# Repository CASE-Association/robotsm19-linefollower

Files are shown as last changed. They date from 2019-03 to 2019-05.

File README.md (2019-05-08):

# CASE line follower robot 2019
Project repository for CASE hardware and software developement for attending the Swedish Robotic Championship 2019.
The robot got 2nd place in the Swedish Robotic Championship 2019.
Diploma

### Contributors
    -   Oskar Johansson
    -   Isak Åslund 
    -   Stefan Larsson

### Structure
    -   Software - All code for running the robot, implemented on Arduino   
    -   Hardware - PCB and hardware design
        -   Schematics for Arduino & STM32F103C8

### Pictures
[Picture album](https://imgur.com/a/kjrejrC)

**V0.1**
Initial Concept

**V0.2**
Working prototype

**V1.0**
Competition design

**PCB**
Two PCBs was designed, one for arduino and one for STM32.
Due to battery being applied to the VB pin on the STM32 it burned up. 
This caused us to use an arduino nano with breadboard instead. 
Since then a updated PCB has been made.
CASE STm32 PCB

### Pinout Help
https://components101.com/microcontrollers/arduino-nano

### Info for development
IDE - Visual Studio Code + PlattformIO
If you want to simplify development change the formatter for cpp to the following:
"{ BasedOnStyle: Google, IndentWidth: 4, ColumnLimit: 0}", more info [here](https://stackoverflow.com/questions/46111834/format-curly-braces-on-same-line-in-c-vscode)

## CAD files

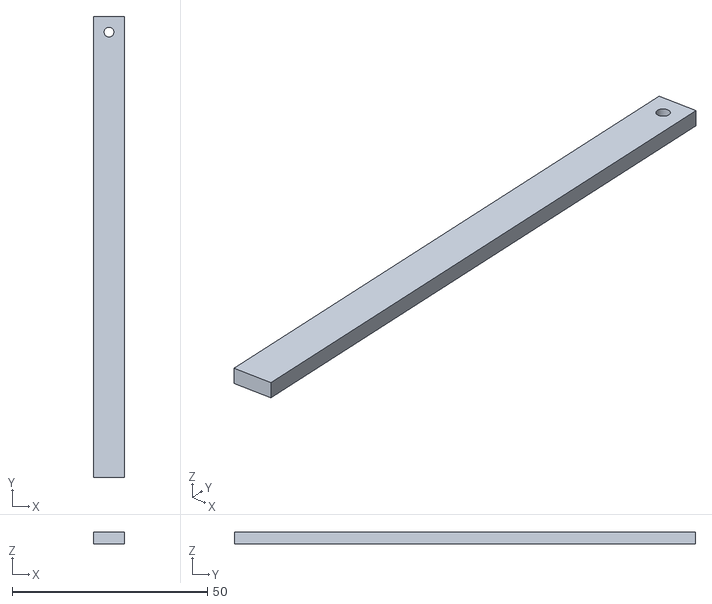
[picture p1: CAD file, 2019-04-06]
hardware/sensorExtender.stl
8.00 x 118.0 x 3.00

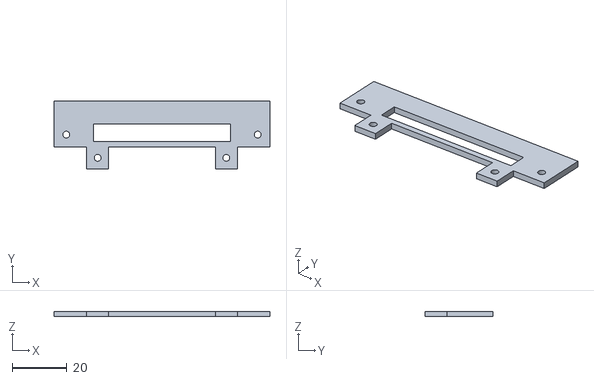
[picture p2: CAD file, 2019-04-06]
hardware/sensormount.stl
78.9 x 24.7 x 2.00

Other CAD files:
hardware/cad/Body.ipt

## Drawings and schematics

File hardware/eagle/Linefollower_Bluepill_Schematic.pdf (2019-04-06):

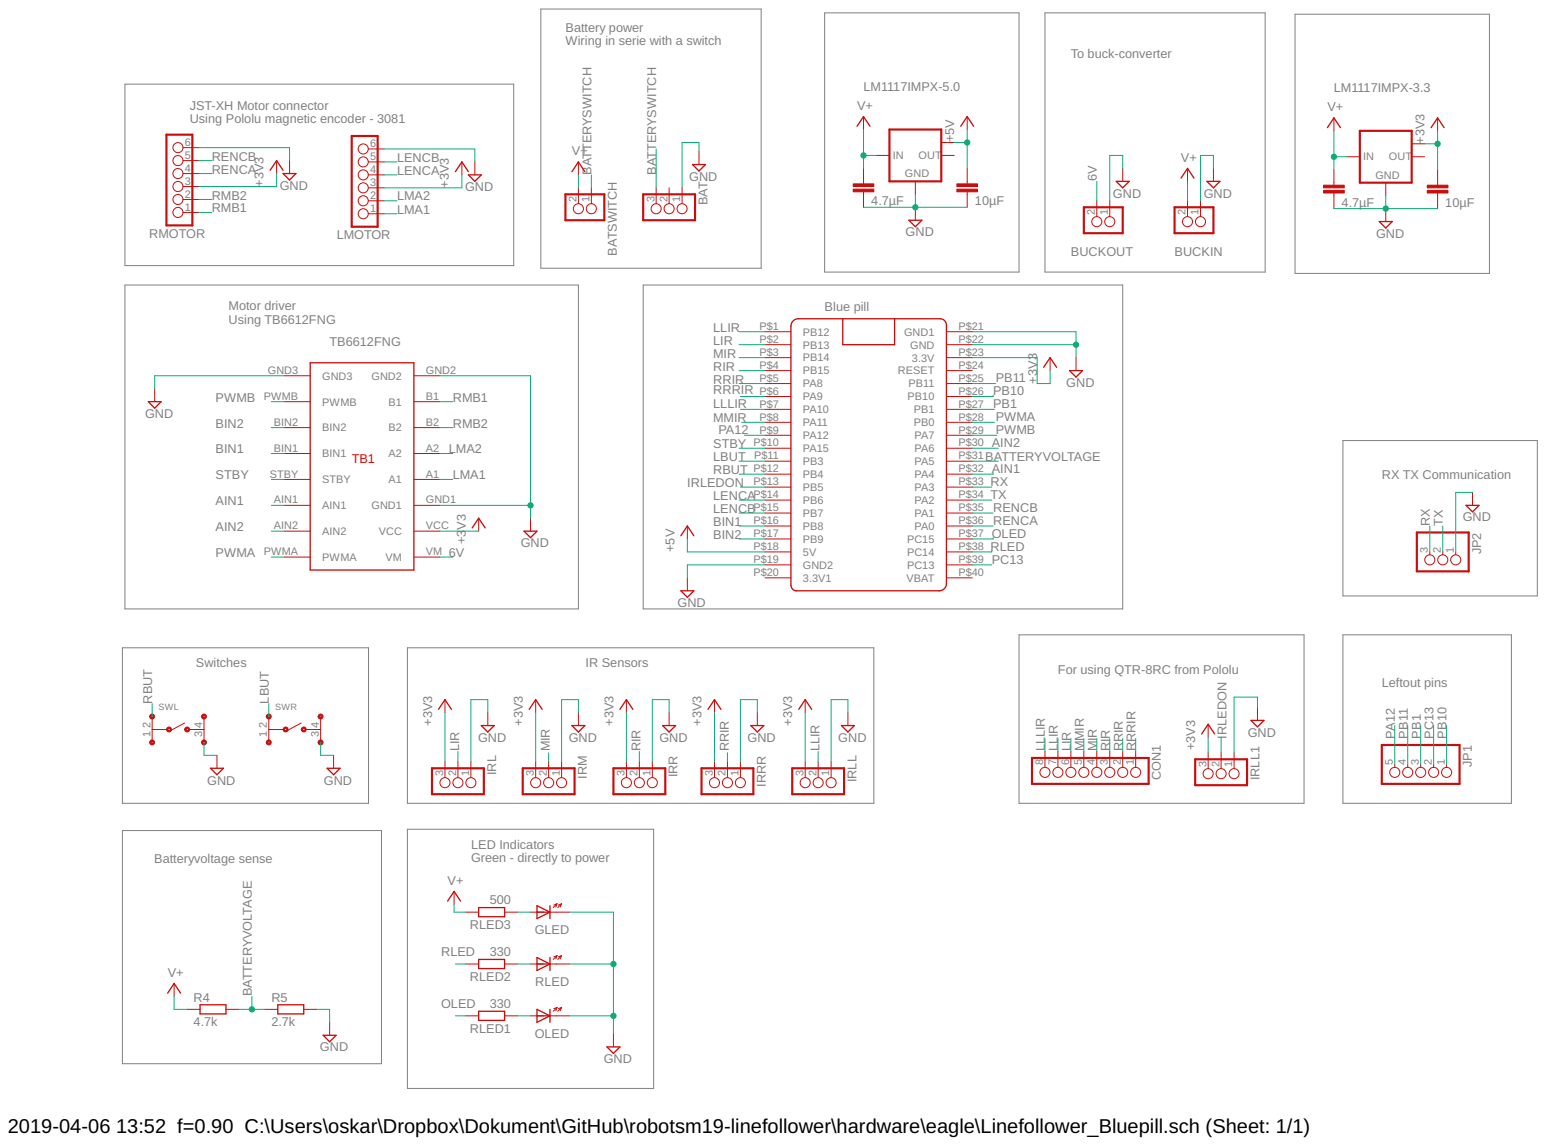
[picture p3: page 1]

Battery power Wiring in serie with a switch

JST-XH Motor connector Using Pololu magnetic encoder - 3081

For using QTR-8RC from Pololu

LED Indicators Green - directly to power

2019-04-06 13:52 f=0.90 C:\Users\oskar\Dropbox\Dokument\GitHub\robotsm19-linefollower\hardware\eagle\Linefollower_Bluepill.sch (Sheet: 1/1)

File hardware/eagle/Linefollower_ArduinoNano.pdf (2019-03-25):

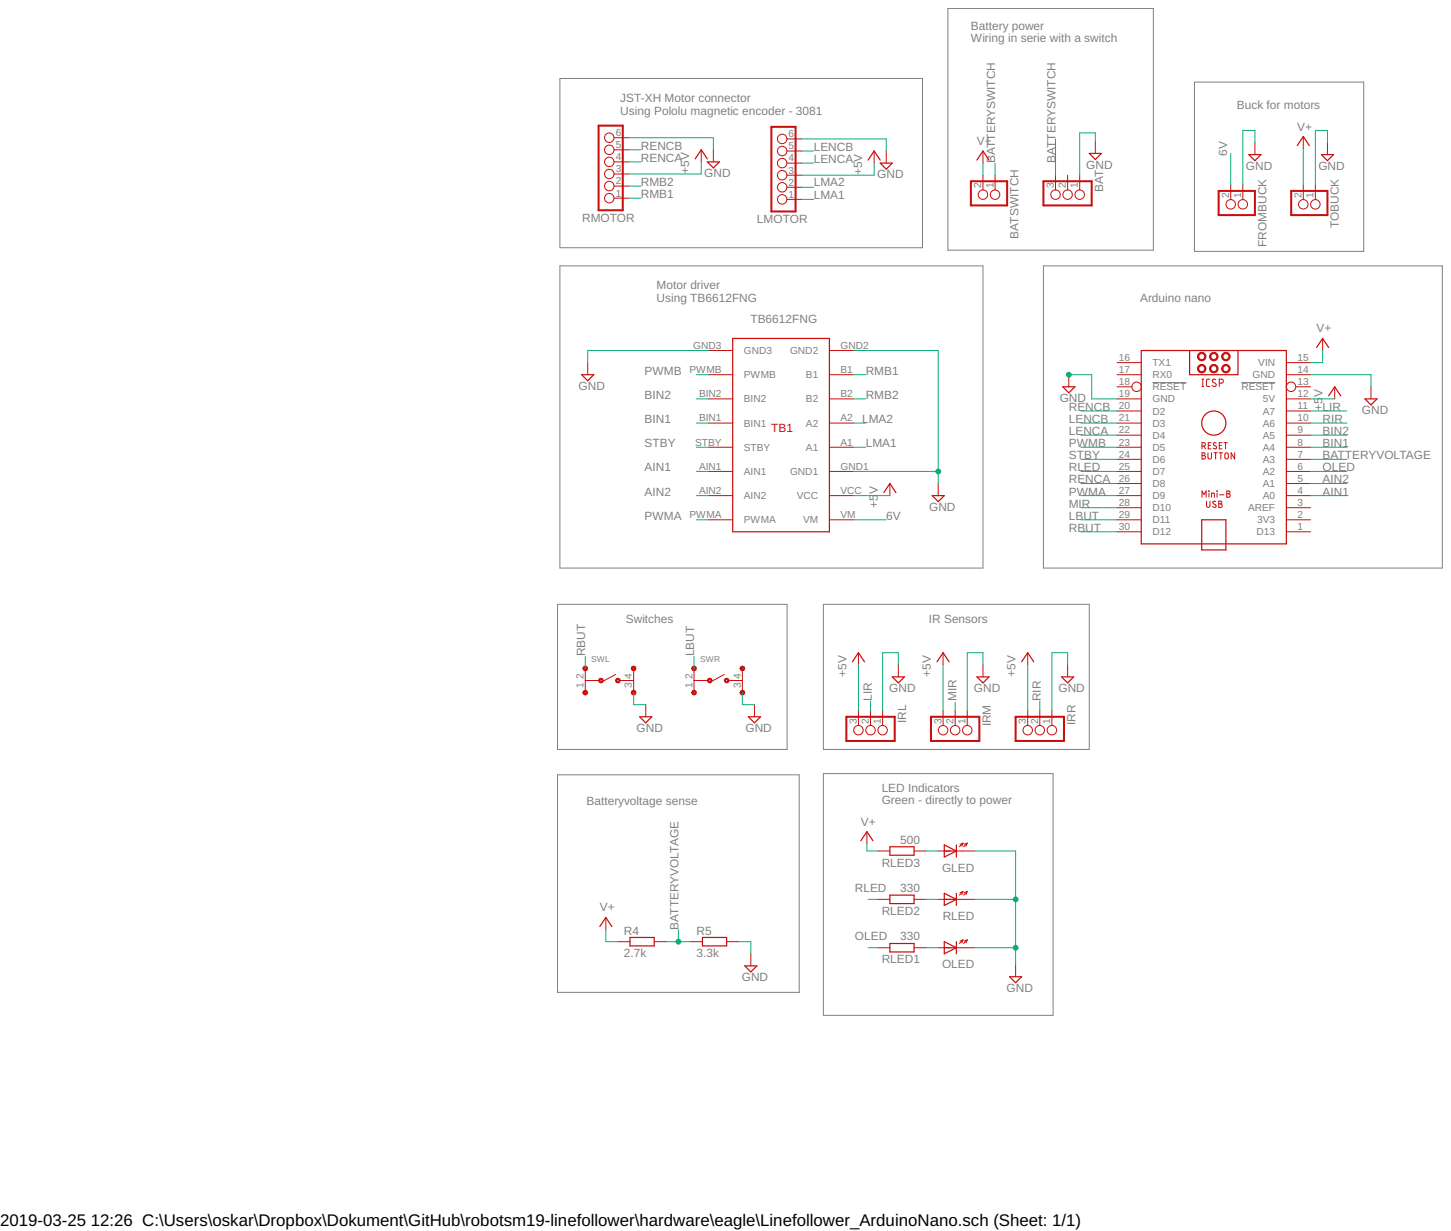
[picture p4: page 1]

Battery power Wiring in serie with a switch

JST-XH Motor connector Using Pololu magnetic encoder - 3081

LED Indicators Green - directly to power

2019-03-25 12:26 C:\Users\oskar\Dropbox\Dokument\GitHub\robotsm19-linefollower\hardware\eagle\Linefollower_ArduinoNano.sch (Sheet: 1/1)

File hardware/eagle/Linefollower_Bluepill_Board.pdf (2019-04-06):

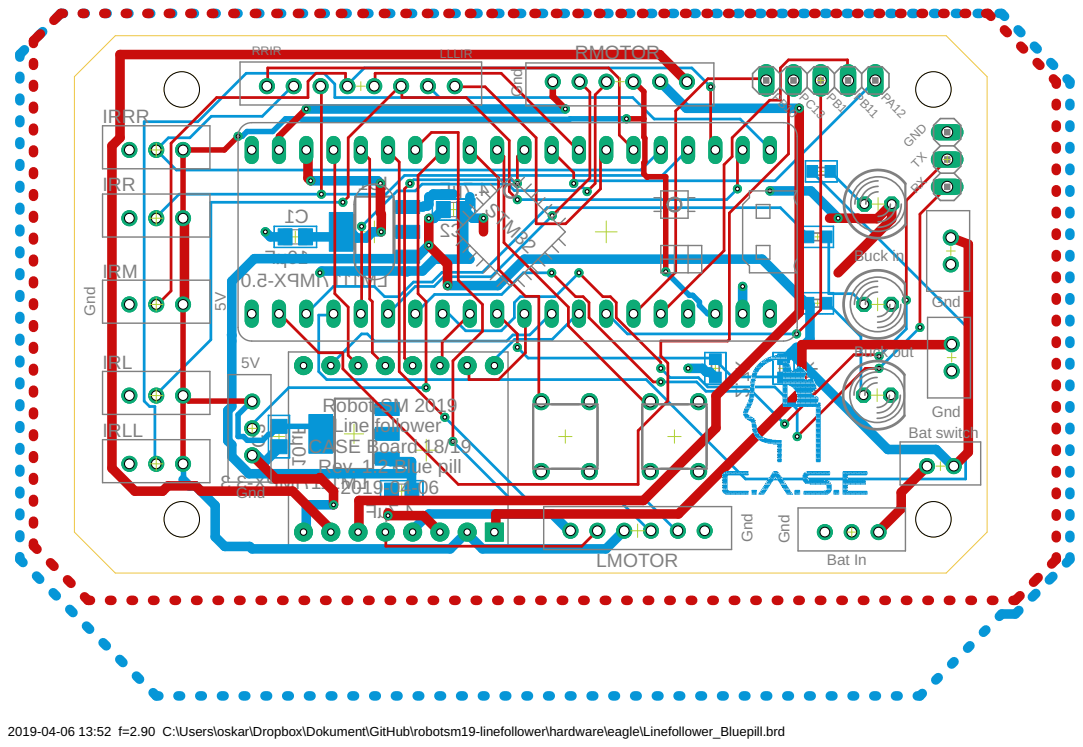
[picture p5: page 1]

2019-04-06 13:52 f=2.90 C:\Users\oskar\Dropbox\Dokument\GitHub\robotsm19-linefollower\hardware\eagle\Linefollower_Bluepill.brd

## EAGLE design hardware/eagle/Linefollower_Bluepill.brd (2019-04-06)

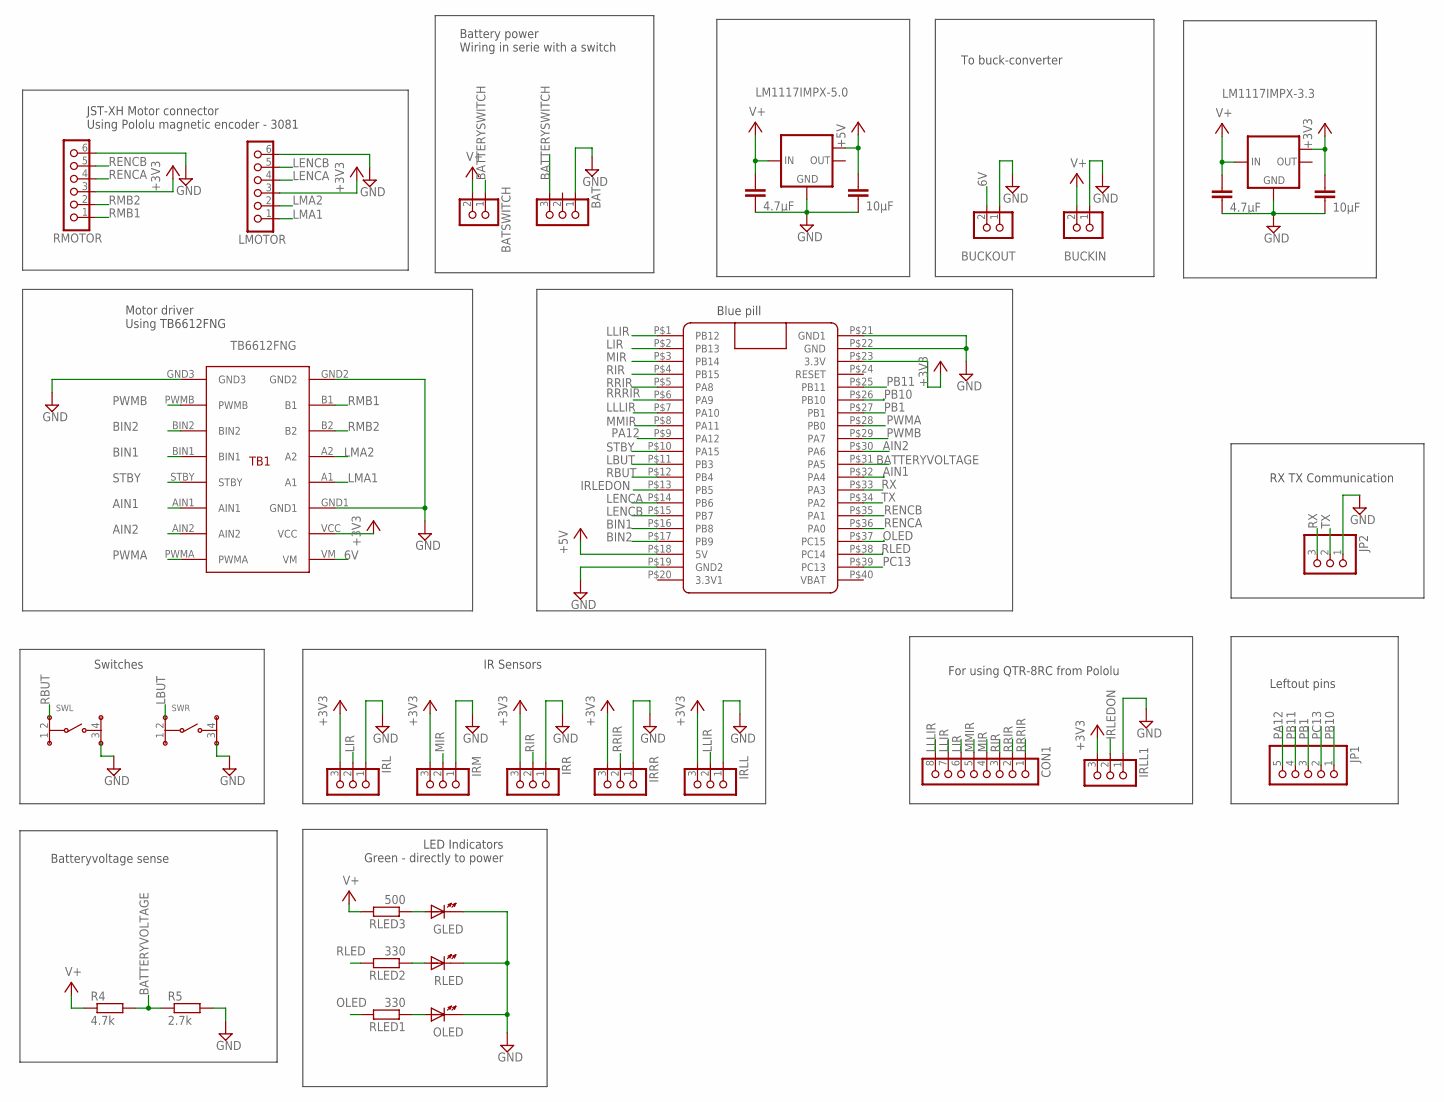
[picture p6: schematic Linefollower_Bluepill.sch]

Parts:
BAT: EH_B3B-EH; B3B-EH
BATSWITCH: EH_B2B-EH; B2B-EH
BUCKIN: EH_B2B-EH; B2B-EH
BUCKOUT: EH_B2B-EH; B2B-EH
C1, C3: 10µF; C0805
C2, C4: 4.7µF; C0805
CON1: EH_B8B-EH; B8B-EH
GLED: LED5MM
IC1: LM1117IMPX-5.0; SOT223
IC3: LM1117IMPX-3.3; SOT223
IRL: EH_B3B-EH; B3B-EH
IRLL, IRLL1: EH_B3B-EH; B3B-EH
IRM: EH_B3B-EH; B3B-EH
IRR: EH_B3B-EH; B3B-EH
IRRR: EH_B3B-EH; B3B-EH
JP1: PINHD-1X5; 1X05
JP2: PINHD-1X3; 1X03
LMOTOR: EH_B6B-EH; B6B-EH
OLED: LED5MM
R4: 4.7k; R0603
R5: 2.7k; R0603
RLED: LED5MM
RLED1, RLED2: 330; R0603
RLED3: 500; R0603
RMOTOR: EH_B6B-EH; B6B-EH
SWL: SKHHA/D
SWR: SKHHA/D
TB1: TB6612FNG
U$1: BLUE_PILL

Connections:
6V: BUCKOUT.2, TB1.VM
+3V3: C3.1, IC3.TAB (OUT1), IRL.3, IRLL.3, IRLL1.3, IRM.3, IRR.3, IRRR.3, LMOTOR.3, RMOTOR.3, TB1.VCC, U$1.P$23 (3.3V)
+5V: C1.1, IC1.TAB (OUT1), U$1.P$18 (5V)
AIN1: TB1.AIN1, U$1.P$32 (PA4)
AIN2: TB1.AIN2, U$1.P$30 (PA6)
BATTERYSWITCH: BAT.3, BATSWITCH.1
BATTERYVOLTAGE: R4.2, R5.1, U$1.P$31 (PA5)
BIN1: TB1.BIN1, U$1.P$16 (PB8)
BIN2: TB1.BIN2, U$1.P$17 (PB9)
GND: BAT.1, BUCKIN.1, BUCKOUT.1, C1.2, C2.2, C3.2, C4.2, GLED.K, IC1.1 (GND), IC3.1 (GND), IRL.1, IRLL.1, IRLL1.1, IRM.1, IRR.1, IRRR.1, JP2.1, LMOTOR.6, OLED.K, R5.2, RLED.K, RMOTOR.6, SWL.3, SWR.3, TB1.GND1, TB1.GND2, TB1.GND3, U$1.P$19 (GND2), U$1.P$21 (GND1), U$1.P$22 (GND)
IRLEDON: IRLL1.2, U$1.P$13 (PB5)
LBUT: SWR.2, U$1.P$11 (PB3)
LENCA: LMOTOR.4, U$1.P$14 (PB6)
LENCB: LMOTOR.5, U$1.P$15 (PB7)
LIR: CON1.6, IRL.2, U$1.P$2 (PB13)
LLIR: CON1.7, IRLL.2, U$1.P$1 (PB12)
LLLIR: CON1.8, U$1.P$7 (PA10)
LMA1: LMOTOR.1, TB1.A1
LMA2: LMOTOR.2, TB1.A2
MIR: CON1.4, IRM.2, U$1.P$3 (PB14)
MMIR: CON1.5, U$1.P$8 (PA11)
unnamed: GLED.A, RLED3.1
unnamed: RLED.A, RLED2.1
unnamed: OLED.A, RLED1.1
OLED: RLED1.2, U$1.P$37 (PC15)
PA12: JP1.5, U$1.P$9 (PA12)
PB1: JP1.3, U$1.P$27 (PB1)
PB10: JP1.1, U$1.P$26 (PB10)
PB11: JP1.4, U$1.P$25 (PB11)
PC13: JP1.2, U$1.P$39 (PC13)
PWMA: TB1.PWMA, U$1.P$28 (PB0)
PWMB: TB1.PWMB, U$1.P$29 (PA7)
RBUT: SWL.2, U$1.P$12 (PB4)
RENCA: RMOTOR.4, U$1.P$36 (PA0)
RENCB: RMOTOR.5, U$1.P$35 (PA1)
RIR: CON1.3, IRR.2, U$1.P$4 (PB15)
RLED: RLED2.2, U$1.P$38 (PC14)
RMB1: RMOTOR.1, TB1.B1
RMB2: RMOTOR.2, TB1.B2
RRIR: CON1.2, IRRR.2, U$1.P$5 (PA8)
RRRIR: CON1.1, U$1.P$6 (PA9)
RX: JP2.3, U$1.P$33 (PA3)
STBY: TB1.STBY, U$1.P$10 (PA15)
TX: JP2.2, U$1.P$34 (PA2)
V+: BATSWITCH.2, BUCKIN.2, C2.1, C4.1, IC1.3 (IN), IC3.3 (IN), R4.1, RLED3.2

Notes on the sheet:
JST-XH Motor connector Using Pololu magnetic encoder - 3081
Motor driver Using TB6612FNG
Battery power Wiring in serie with a switch
LED Indicators Green - directly to power
IR Sensors
Switches
Batteryvoltage sense
Blue pill
For using QTR-8RC from Pololu
Leftout pins
RX TX Communication
To buck-converter

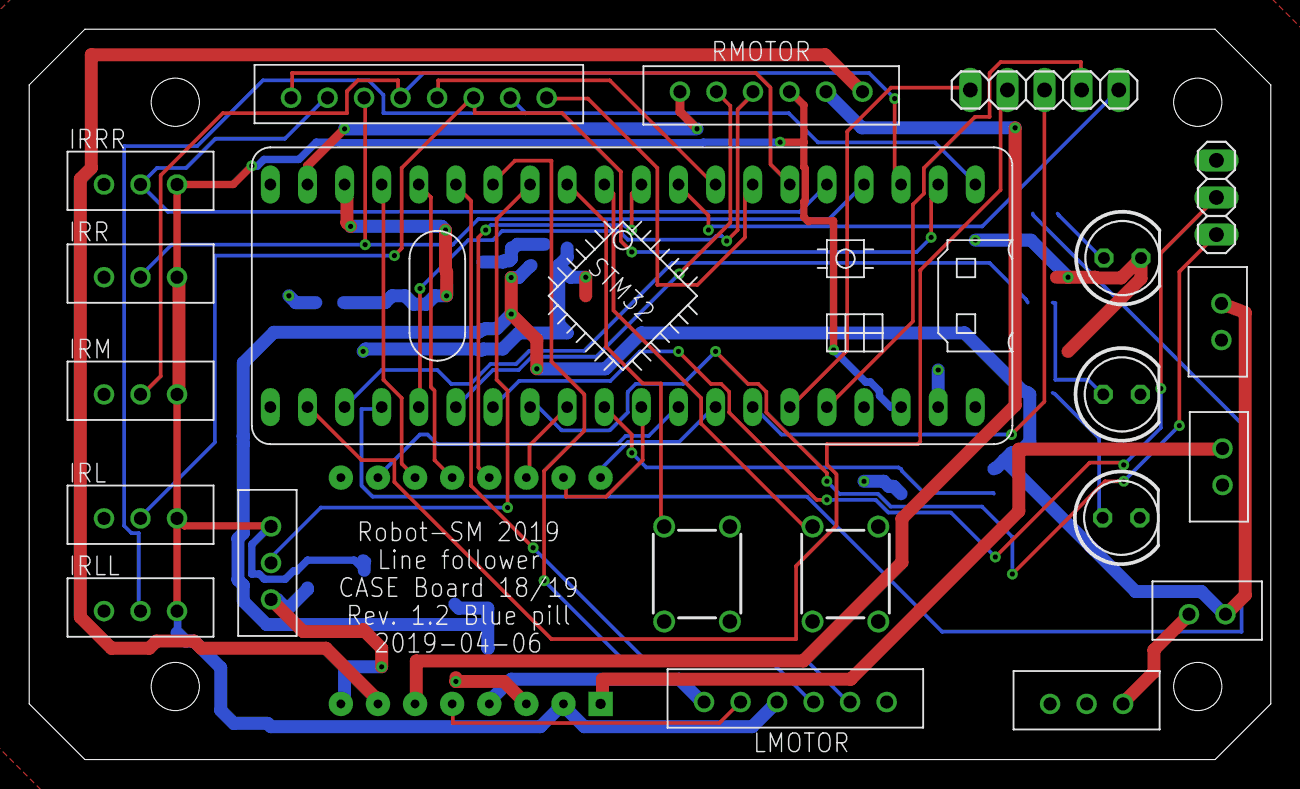
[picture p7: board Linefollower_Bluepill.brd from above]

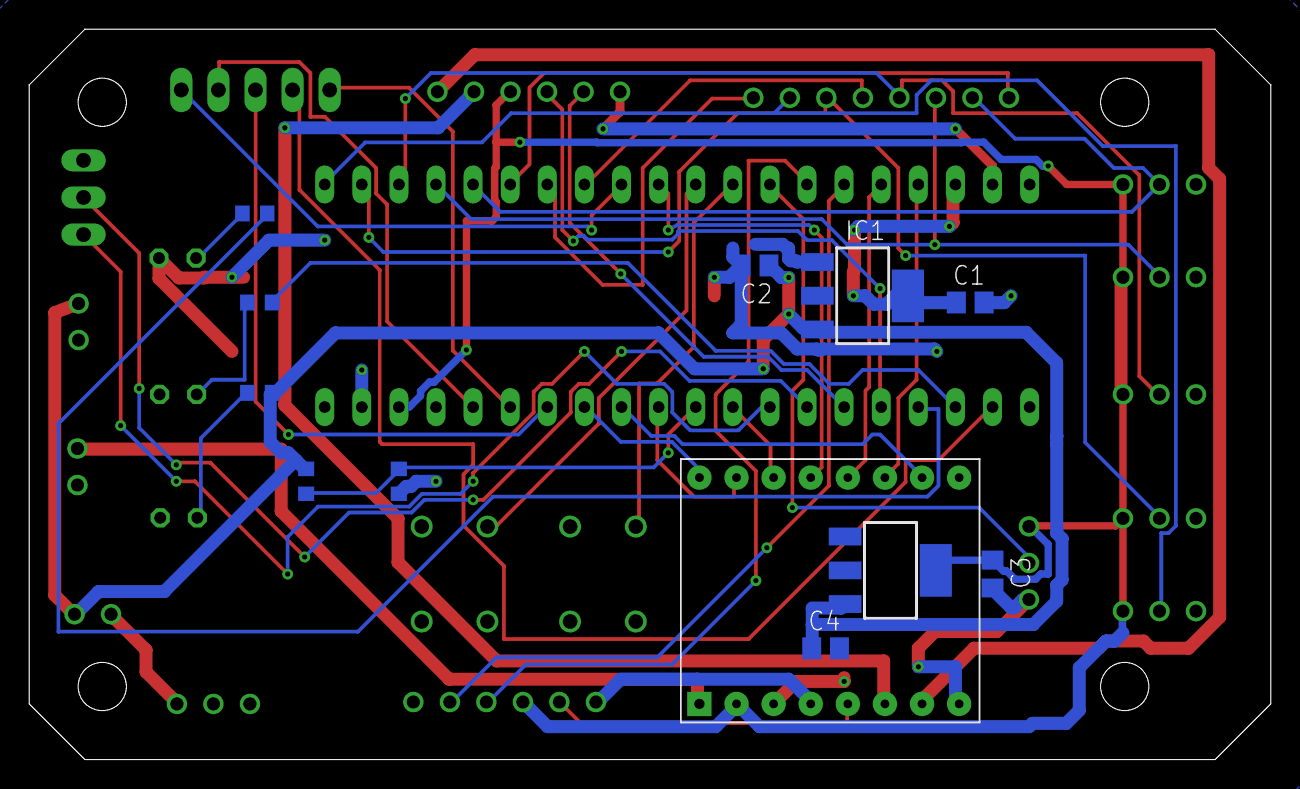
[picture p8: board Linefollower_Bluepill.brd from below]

Board: 2 copper layers, 85.0 x 50.0 mm, 33 parts (12 on the bottom side), 45 nets.

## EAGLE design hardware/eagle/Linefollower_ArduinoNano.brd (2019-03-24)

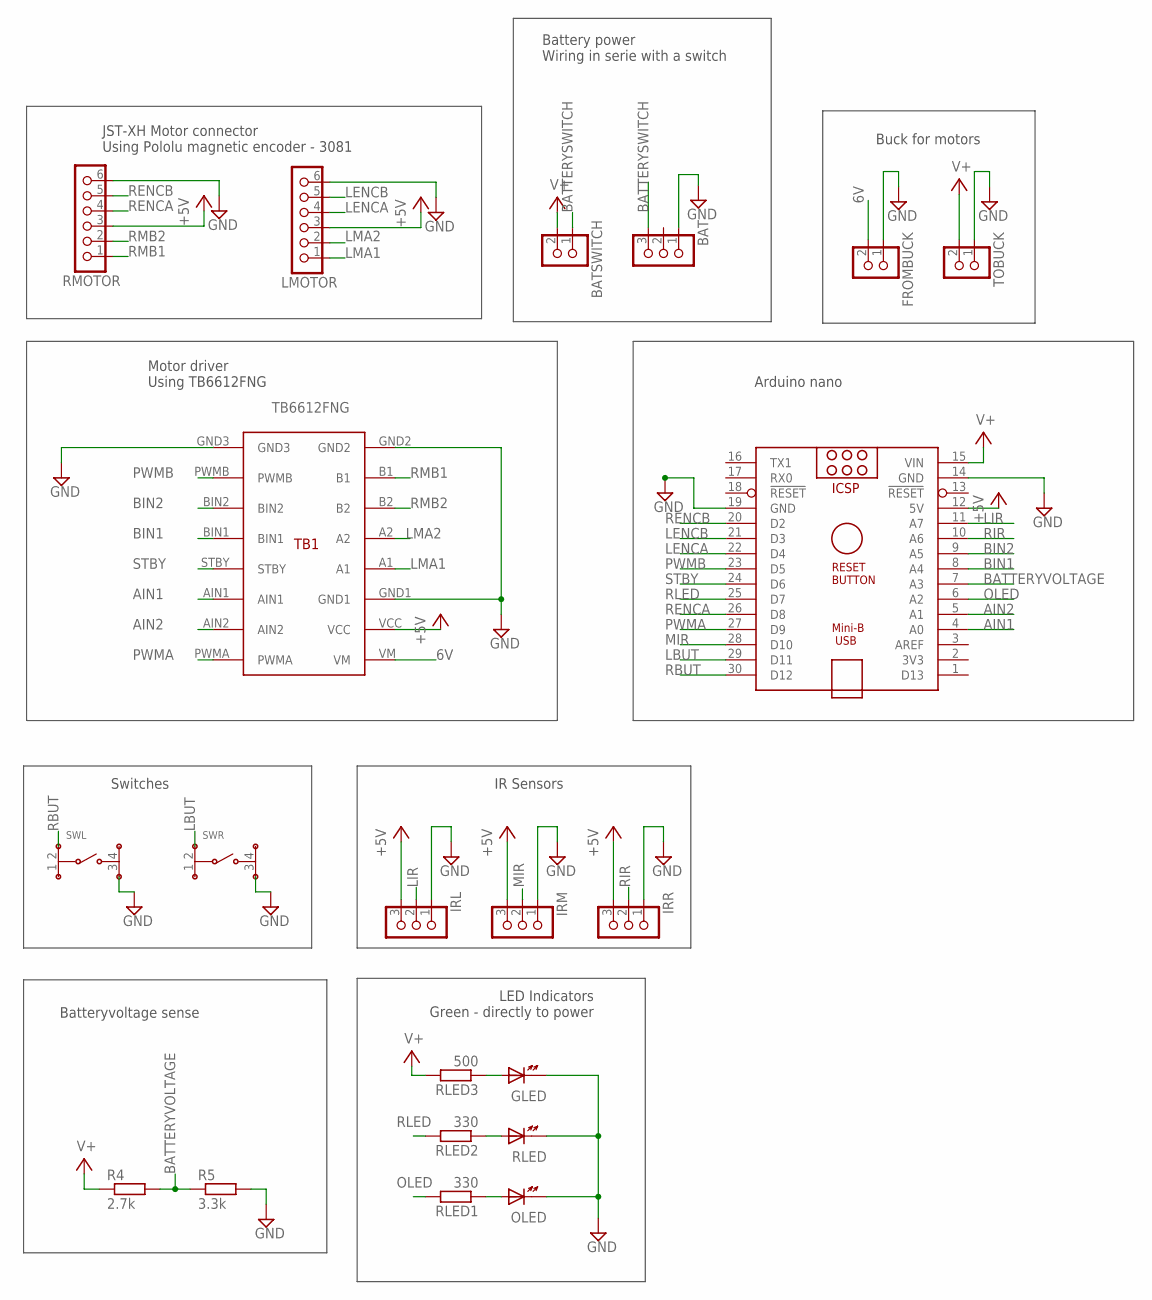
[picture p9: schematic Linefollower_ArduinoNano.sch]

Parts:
ARDUINO_NANO1: ARDUINO_NANO
BAT: EH_B3B-EH; B3B-EH
BATSWITCH: EH_B2B-EH; B2B-EH
FROMBUCK: EH_B2B-EH; B2B-EH
GLED: LED5MM
IRL: EH_B3B-EH; B3B-EH
IRM: EH_B3B-EH; B3B-EH
IRR: EH_B3B-EH; B3B-EH
LMOTOR: EH_B6B-EH; B6B-EH
OLED: LED5MM
R4: 2.7k; R0603
R5: 3.3k; R0603
RLED: LED5MM
RLED1, RLED2: 330; R0603
RLED3: 500; R0603
RMOTOR: EH_B6B-EH; B6B-EH
SWL: SKHHA/D
SWR: SKHHA/D
TB1: TB6612FNG
TOBUCK: EH_B2B-EH; B2B-EH

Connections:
6V: FROMBUCK.2, TB1.VM
+5V: ARDUINO_NANO1.12 (5V), IRL.3, IRM.3, IRR.3, LMOTOR.3, RMOTOR.3, TB1.VCC
AIN1: ARDUINO_NANO1.4 (A0), TB1.AIN1
AIN2: ARDUINO_NANO1.5 (A1), TB1.AIN2
BATTERYSWITCH: BAT.3, BATSWITCH.1
BATTERYVOLTAGE: ARDUINO_NANO1.7 (A3), R4.2, R5.1
BIN1: ARDUINO_NANO1.8 (A4), TB1.BIN1
BIN2: ARDUINO_NANO1.9 (A5), TB1.BIN2
GND: ARDUINO_NANO1.14 (GND), ARDUINO_NANO1.19 (GND), BAT.1, FROMBUCK.1, GLED.K, IRL.1, IRM.1, IRR.1, LMOTOR.6, OLED.K, R5.2, RLED.K, RMOTOR.6, SWL.3, SWR.3, TB1.GND1, TB1.GND2, TB1.GND3, TOBUCK.1
LBUT: ARDUINO_NANO1.29 (D11), SWR.2
LENCA: ARDUINO_NANO1.22 (D4), LMOTOR.4
LENCB: ARDUINO_NANO1.21 (D3), LMOTOR.5
LIR: ARDUINO_NANO1.11 (A7), IRL.2
LMA1: LMOTOR.1, TB1.A1
LMA2: LMOTOR.2, TB1.A2
MIR: ARDUINO_NANO1.28 (D10), IRM.2
unnamed: GLED.A, RLED3.1
unnamed: RLED.A, RLED2.1
unnamed: OLED.A, RLED1.1
OLED: ARDUINO_NANO1.6 (A2), RLED1.2
PWMA: ARDUINO_NANO1.27 (D9), TB1.PWMA
PWMB: ARDUINO_NANO1.23 (D5), TB1.PWMB
RBUT: ARDUINO_NANO1.30 (D12), SWL.2
RENCA: ARDUINO_NANO1.26 (D8), RMOTOR.4
RENCB: ARDUINO_NANO1.20 (D2), RMOTOR.5
RIR: ARDUINO_NANO1.10 (A6), IRR.2
RLED: ARDUINO_NANO1.25 (D7), RLED2.2
RMB1: RMOTOR.1, TB1.B1
RMB2: RMOTOR.2, TB1.B2
STBY: ARDUINO_NANO1.24 (D6), TB1.STBY
V+: ARDUINO_NANO1.15 (VIN), BATSWITCH.2, R4.1, RLED3.2, TOBUCK.2

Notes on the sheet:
JST-XH Motor connector Using Pololu magnetic encoder - 3081
Motor driver Using TB6612FNG
Battery power Wiring in serie with a switch
LED Indicators Green - directly to power
IR Sensors
Switches
Arduino nano
Batteryvoltage sense
Buck for motors

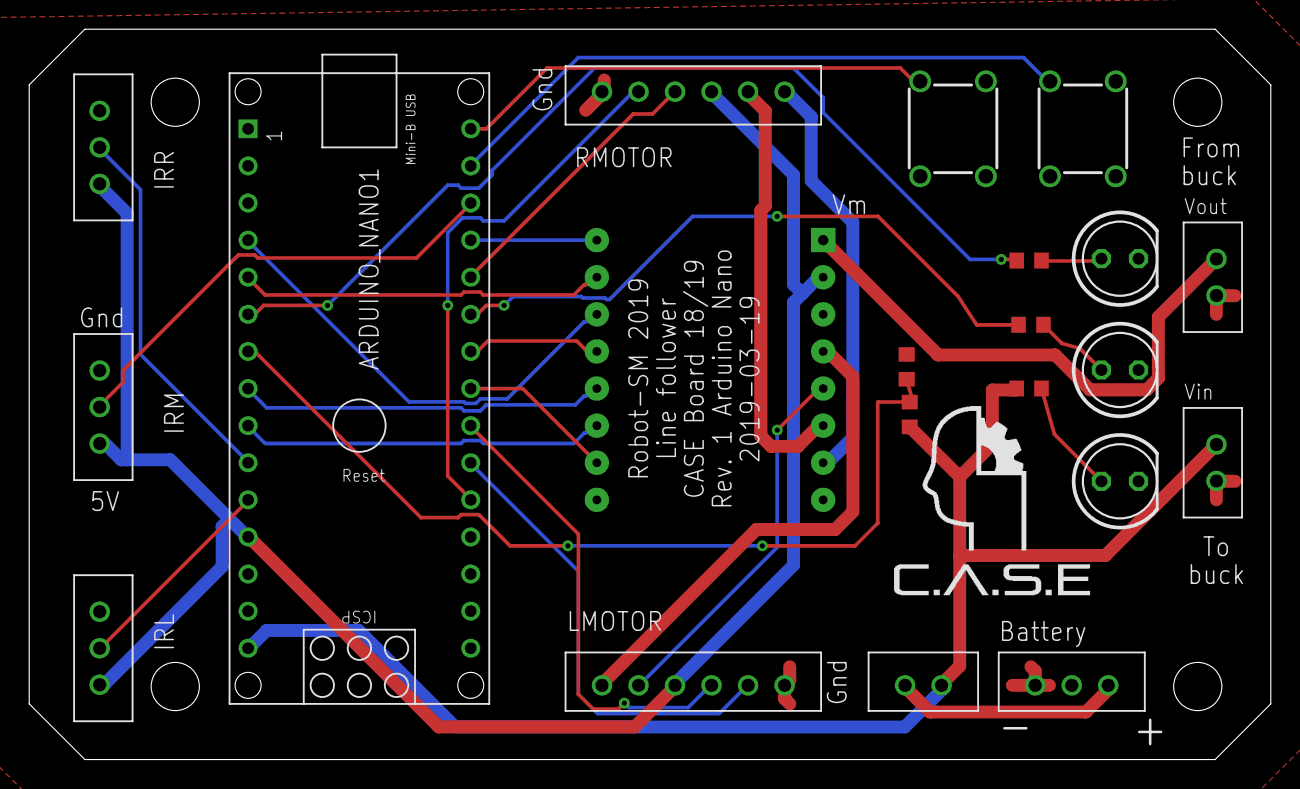
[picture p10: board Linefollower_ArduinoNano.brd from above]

Board: 2 copper layers, 85.0 x 50.0 mm, 21 parts (1 on the bottom side), 31 nets.

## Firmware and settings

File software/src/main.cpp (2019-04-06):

/*
   Code for CASE line following robot that will be attending the Robot Championship in Sweden 2019.
   Authors:
   Oskar Johansson - oskaj@chalmers.se
   Isak Åslund - isakas@chalmers.se
   Stefan Larsson - stel@student.chalmers.se
*/

/*
   Things to implement:
   LED - Implemented - Verified
   Button - Implemented - Verified
   Motor - Implemented - Verified
   Sensors - Implemented - Verified
*/

#include <Arduino.h>
#include "led.h"
#include "button.h"
#include "motor.h"
#include "sensor.h"

void setup() {
    Serial.begin(115200);

    ledSetup();
    buttonSetup();
    motorSetup();
    

    delay(100);
    Serial.println("------  CASE - RobotSM19 - Linefollower  ------");
    Serial.println("------  Press to calibrate  ------");

    while(!readButton());
    LED_O_ON();
    sensorSetup();
    delay(50);
    LED_O_OFF();

    Serial.println("------  Press to START  ------");
    while(!readButton());
    Serial.println("------ Let's go in 1s ------");
    LED_O_ON();
    delay(1000);
}

void loop() {

    //testLEDS();
    //testMotors();  
    //testSensors();
    control();
}

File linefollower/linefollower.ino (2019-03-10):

/*
   Code for CASE line following robot that will be attending the Robot Championship in Sweden 2019.
   Authors:
   Oskar Johansson - email@email.com
   Isak Åslund - aslundisak@gmail.com
*/

/*
   Things to implement:
   LED - ok
   Button - ok
   Motor - ok
   Encoder - (setup, interrupts and basic commands for getting encoder data)
   Control - (Control loop for maintaining a certain speed and acceleration)
   Sensors - (Setup and basic commands for reading data from the sensors)
   Algorithm - (The algorithm used to decide how to drive the robot, this will probably not be needed in the start since the controller will take care of it. Only if we need more advanced techics.
*/


// Important - Rember to only include library files such as <Wire.h> in this file (the main file) because of how the compiler works in Arduino IDE.
#include "led.h"
#include "button.h"
#include "motor.h"


void setup() {
  // put your setup code here, to run once:
  ledSetup();
  //buttonSetup();
  motorSetup();

}

void loop() {

}

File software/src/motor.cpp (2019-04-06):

#include <Arduino.h>
#include "motor.h"

/*
 * @brief Function for setting up the motor driver
 */
void motorSetup(void) {
    pinMode(LEFTMOTOR, OUTPUT);
    pinMode(RIGHTMOTOR, OUTPUT);
    pinMode(AIN1,OUTPUT);
    pinMode(AIN2,OUTPUT);
    pinMode(BIN1,OUTPUT);
    pinMode(BIN2,OUTPUT);
}

/**
 * @brief Function for testing forward and reverse
 * 
 */
void testMotors(void){
    Serial.println("----- Forward -----");
    Serial.println("Left power: 100 -- Right power : 100");
    setLeftPWM(100);
    setRightPWM(100);
    delay(1000);

    Serial.println("----- STOP -----");
    turnMotorsOff();
    delay(2000);

    Serial.println("----- Backwards -----");
    Serial.println("Left power: -100 -- Right power : -100");
    setLeftPWM(-100);
    setRightPWM(-100);
    delay(1000);

    Serial.println("----- STOP -----");
    turnMotorsOff();
    delay(2000);
}

/**
 * @brief Functions for running both motors from zero speed to max and back down. Rotation is forward.
 * 
 */
void motorSweep(void){
    for(int i = 0; i <= 255; i++){
        setLeftPWM(i);
        setRightPWM(i);
        delay(12);
    }

    for(int i = 255; i >= 0; i--){
        setLeftPWM(i);
        setRightPWM(i);
        delay(12);
    }
}

/*
 * @brief Function for adjusting the right motor speed.
 * @param speed (int) The disered raw speed. 
 */
void setRightPWM(int speed) {
    if (speed > 255) {
        speed = 255;
    }
    if (speed < -255) {
        speed = -255;
    }
    if(speed >= 0) {
        digitalWrite(AIN2,LOW);
        digitalWrite(AIN1,HIGH);
        analogWrite(RIGHTMOTOR, speed);
    }
    else {
        digitalWrite(AIN2,HIGH);
        digitalWrite(AIN1,LOW);
        analogWrite(RIGHTMOTOR, -speed);
    }

    
}

/*
 * @brief Function for adjusting the left motor speed.
 * @param speed (int) The disered raw speed. 
 */
void setLeftPWM(int speed) {
    if (speed > 255) {
        speed = 255;
    }
    if (speed < -255) {
        speed = -255;
    }
    if(speed >= 0) {
        digitalWrite(BIN2,LOW);
        digitalWrite(BIN1,HIGH);
        analogWrite(LEFTMOTOR, speed);
    }
    else {
        digitalWrite(BIN2,HIGH);
        digitalWrite(BIN1,LOW);
        analogWrite(LEFTMOTOR, -speed);
    }
}

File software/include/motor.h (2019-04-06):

#ifndef MOTOR_H
#define MOTOR_H

#define RIGHTMOTOR 10 // D10 - Right Motor 
#define LEFTMOTOR 11  // D11 - Left Motor 
#define AIN1 PIN_A4
#define AIN2 PIN_A5
#define BIN1 PIN_A3 
#define BIN2 PIN_A2 

void motorSetup(void);
void setLeftPWM(int);
void setRightPWM(int);
void testMotors(void);
void motorSweep(void);


#define turnMotorsOff(void) setLeftPWM(0); setRightPWM(0)

#endif

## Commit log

2019-03-10 Initial setup + Button/LED/Motor
    Initialization of the project and some of the LED/BUTTON/MOTOR functions.
2019-03-10 Motor functions
    Implementation for basic motor functionality
2019-03-10 Encoder implementation
2019-03-10 Encoder implementation (updated)
    Coded in the wrong repository so there was no implementation on the last commit. This one contains the implementation of the encoder.
2019-03-18 Updated plattform to PlattformIO
    Because the Arduino IDE gets cluttered with tabs and other stuff when the project gets larger we decided to switch the development plattform to "Plattform IO", we will now develop in visual studio co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
2019-03-18 Rewire + Cleanup
    Cleaned up code with formatting in VS CODE, soldered breadboard and had to redo some definitions becuase some pins were not compatible.
    [main.cpp, motor.cpp, motor.h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]
2019-03-18 LED Implementation + Verification
    LED now works as it should on hardware.
2019-03-18 Sensor implementation
    Implemeted IR line sensors (Flying-Fish MH-Sensor).
    Also did some motor testing and adjustments.
2019-03-19 encoder: cleanup
2019-03-19 First implementation of velocity control
    Not working because of different time standards.
    [main.cpp, motor.cpp]
2019-03-19 voltage: init commit
2019-03-19 Ok P values for trans/rot regulator
2019-03-19 encoder: changed to register reads
2019-03-20 Redid implementation to be dumb
    No PID controller is no longer used fo turn and velocity. It is now dumb.
    [main.cpp, motor.cpp]
2019-03-24 Testing for STM32
2019-03-24 New folder structure
    Since a PCB was made the folder structure was changed to have both hardware and software.
2019-03-24 Rev 1.1
    This one was ordered 2019-03-20
    [Linefollower_Bluepill.brd, Linefollower_Bluepill.sch]
2019-03-24 Rev 1
    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
    [Linefollower_ArduinoNano.brd, Linefollower_ArduinoNano.sch]
2019-03-25 Added schematic PDF
2019-03-27 Change on silkmask
    Buck In and Buck Out was at wrong position.
    [Linefollower_Bluepill.brd]
2019-03-27 Hardware STL files
    [sensorExtender.stl, sensormount.stl]
2019-03-27 First rev
    Only a basic base body. Not complete
    [Body.ipt]
2019-04-04 Rewrite of LED
2019-04-04 Rewrote Button
2019-04-04 Rewrote Motor
2019-04-04 Removed encoder
    It was removed since this project is done on arduino nano and there are not enough interrupt pins to make QTR sensor, and encoders
2019-04-04 Verified leds, sensors and motors
2019-04-06 Robot SM 19 Final heat
    All code for final heat Robot SM 19. <10 s.
2019-04-06 QTR Sensor lib
    Library for QTR Sensor
2019-04-06 Removed Vin to VBat
    Removed wrong connection to bluepill. It caused the blue pill's magic smoke to escape. Resolves #4
    [Linefollower_Bluepill.brd, Linefollower_Bluepill.sch]
